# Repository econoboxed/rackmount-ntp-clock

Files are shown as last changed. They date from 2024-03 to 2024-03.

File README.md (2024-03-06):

# rackmount-ntp-clock

[](https://www.arduino.cc/)
[](https://www.adafruit.com/)

This project uses an adafruit feather rp2040, an ethernet hat, and a 7-Segment Display to display the time. The project is meant to be rackmounted in 10-inch, or half rack.

## Bill of Materials:

1. [Adafruit Feather RP2040](https://www.adafruit.com/product/4884)
2. [Adafruit Ethernet Featherwing](https://www.adafruit.com/product/3201)
3. [Adafruit 7seg](https://www.adafruit.com/product/1269)
4. [Sparkfun USB-C breakout Board](https://www.sparkfun.com/products/15100)

## Assembly:

All items are meant to friction-fit into the single printed part.

Install the ethernet featherwing on the feather rp2040, and connect the 7-segment display via **both** the i2c connector, and 3.3v power (labeled '+' and '-' on the 7seg PCB).

Optionally connect "VBUS and "GND" on the sparkfun breakout board to "USB" and "GND" on the rp2040 if you wish to have a backwards-facing usb (otherwise rails may impede the usb-c cord).

Flash the rp2040 with the provided .ino file in the repository. Some libraries are required, such as Ethernet, SPI, Adafruit GFX, Adafruit_LED_Backpack_Library.

## Printing:

I printed the plate on my Prusamk3s+, the .3mf project file is included, this file includes the keystone, which I did not model in freeCAD.

The part was printed in PLA, layer height was .3mm, with a gyroid infill of 15%.

I printed with no supports, but the mounting pegs for the usb-c breakout board needed to be filed to fit.

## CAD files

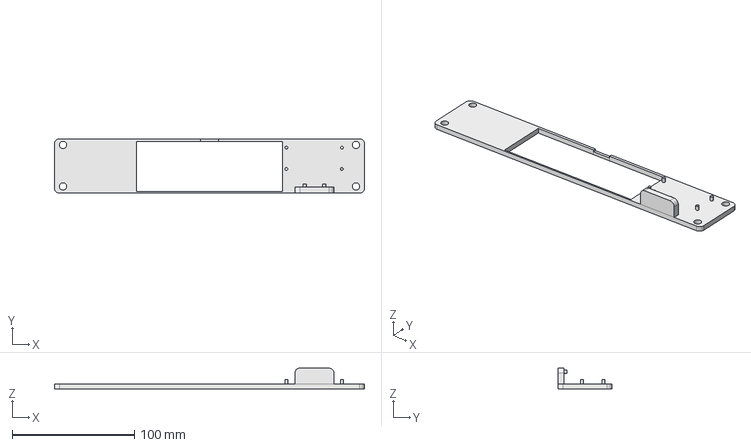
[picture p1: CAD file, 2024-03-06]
rackmount-ntp-clock.FCStd
254.0 x 44.5 x 17.0 mm

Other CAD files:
rackmount-ntp-clock.3mf
rackmount-ntp-clock.stl

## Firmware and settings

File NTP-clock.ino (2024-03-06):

/*
 Original Udp NTP Client code by
 by Michael Margolis, Tom Igoe, Arturo Guadalupi

 This code is in the public domain.

 */

#include <Wire.h> // Enable this line if using Arduino Uno, Mega, etc.
#include <Adafruit_GFX.h>
#include "Adafruit_LEDBackpack.h"
#include <SPI.h>
#include <Ethernet.h>
#include <EthernetUdp.h>

Adafruit_7segment matrix = Adafruit_7segment();

// Enter a MAC address for your controller below.
// Newer Ethernet shields have a MAC address printed on a sticker on the shield
byte mac[] = {
		0xDE, 0xAD, 0xBE, 0xEF, 0xFE, 0xED};

unsigned int localPort = 8888;
const char timeServer[] = "192.168.2.10";
const int NTP_PACKET_SIZE = 48;
byte packetBuffer[NTP_PACKET_SIZE];

// long to store UNIX time
unsigned long secsSince1900;

// update to your local time zone
const int timezone = -4;

// change to true if you wish for the dots to flash
const bool flash = false;

// A UDP instance to let us send and receive packets over UDP
EthernetUDP Udp;

void setup()
{

	// Begin matrix display
	matrix.begin(0x70);

	// You can use Ethernet.init(pin) to configure the CS pin
	Ethernet.init(10); // Most Arduino shields

	// start Ethernet and UDP
	if (Ethernet.begin(mac) == 0)
	{
		Serial.println("Failed to configure Ethernet using DHCP");
		// Check for Ethernet hardware present
		if (Ethernet.hardwareStatus() == EthernetNoHardware)
		{
			Serial.println("Ethernet shield was not found.  Sorry, can't run without hardware. :(");
		}
		else if (Ethernet.linkStatus() == LinkOFF)
		{
			Serial.println("Ethernet cable is not connected.");
		}
		// no point in carrying on, so do nothing forevermore:
		while (true)
		{
			delay(1);
		}
	}
	Udp.begin(localPort);
}

void loop()
{
	sendNTPpacket(timeServer); // send an NTP packet to a time server

	// wait to see if a reply is available
	if (flash)
	{
		for (int i = 0; i <= 2; i++)
		{
			matrix.drawColon(i % 2 == 1);
			matrix.writeDisplay();
			delay(1000);
		}
	}
	else
	{
		delay(2000);
	}

	// if the UDP request recieved a packet, update the clock with the information from the time server
	if (Udp.parsePacket())
	{
		matrix.writeDigitRaw(0, 0x04);
		matrix.drawColon(true);

		// We've received a packet, read the data from it
		Udp.read(packetBuffer, NTP_PACKET_SIZE); // read the packet into the buffer
		// the timestamp starts at byte 40 of the received packet and is four bytes,
		// or two words, long. First, extract the two words:

		unsigned long highWord = word(packetBuffer[40], packetBuffer[41]);
		unsigned long lowWord = word(packetBuffer[42], packetBuffer[43]);
		// combine the four bytes (two words) into a long integer
		// this is NTP time (seconds since Jan 1 1900):
		secsSince1900 = highWord << 16 | lowWord;

		// if the UPD request got no responce, update the clock based on the delay since the last update
		// This will not keep perfect time, and will slowly drift out-of-sync until a new packet is able to properly update the clock
		// An LED in the upper left of the clock is illuminated to show this state to the user
	}
	else
	{
		matrix.writeDigitRaw(2, 0x04);
		secsSince1900 += 12;
	}

	// now convert NTP or estimated time into everyday time:
	// Unix time starts on Jan 1 1970. In seconds, that's 2208988800:
	const unsigned long seventyYears = 2208988800UL;

	// subtract seventy years:
	unsigned long epoch = secsSince1900 - seventyYears;

	// subtract seconds based on what the timezone is set to
	epoch = epoch + (timezone * 3600);

	// draw the display digit by digit
	matrix.writeDigitNum(0, (((epoch % 86400L) / 3600) / 10));
	matrix.writeDigitNum(1, (((epoch % 86400L) / 3600) % 10));
	matrix.writeDigitNum(3, (((epoch % 3600) / 60) / 10));
	matrix.writeDigitNum(4, (((epoch % 3600) / 60) % 10));

	matrix.writeDisplay();

	// wait ten seconds before asking for the time again
	if (flash)
	{
		for (int i = 0; i <= 10; i++)
		{
			matrix.drawColon(i % 2 == 0);
			matrix.writeDisplay();
			delay(1000);
		}
	}
	else
	{
		delay(10000);
	}

	Ethernet.maintain();
}

// send an NTP request to the time server at the given address
void sendNTPpacket(const char *address)
{
	// set all bytes in the buffer to 0
	memset(packetBuffer, 0, NTP_PACKET_SIZE);
	// Initialize values needed to form NTP request
	// (see URL above for details on the packets)
	packetBuffer[0] = 0b11100011; // LI, Version, Mode
	packetBuffer[1] = 0;					// Stratum, or type of clock
	packetBuffer[2] = 6;					// Polling Interval
	packetBuffer[3] = 0xEC;				// Peer Clock Precision
	// 8 bytes of zero for Root Delay & Root Dispersion
	packetBuffer[12] = 49;
	packetBuffer[13] = 0x4E;
	packetBuffer[14] = 49;
	packetBuffer[15] = 52;

	// all NTP fields have been given values, now
	// you can send a packet requesting a timestamp:
	Udp.beginPacket(address, 123); // NTP requests are to port 123
	Udp.write(packetBuffer, NTP_PACKET_SIZE);
	Udp.endPacket();
}

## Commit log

2024-03-06 added arduino file
2024-03-06 added freecad / prusa files
    [rackmount-ntp-clock.3mf, rackmount-ntp-clock.FCStd, rackmount-ntp-clock.stl]
